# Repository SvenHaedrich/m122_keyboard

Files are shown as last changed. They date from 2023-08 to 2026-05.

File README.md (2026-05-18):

# m122_keyboard

Project for an IBM M122 keyboard controller

This is a project that replaces the original part from IBM with a nice modern solution.
It features a nRF52840 microcontroller and allows to use the keyboard
via USB connector, or via Bluetooth.

The firmware is based on the [ZMK](https://github.com/zmkfirmware) project.

Assembled PCB

## Parts

Beside the assembled PCB you require:

- A matching IBM Keyboard
- An external LiPO cell - the unit was designed with a LP103048JU 1.500 m Ah cell in mind
- One 8 pin connector for the flat flex coming from the keyboad 5-520315-8 from [AMP](doc/ENG_CD_520355_L2.pdf) DigiKey P/N 5-520315-8-ND
- One 20 pin connector for the flat flex coming from the keyboad 7-520355-0 from [AMP](doc/ENG_CD_520355_L2.pdf) DigiKey P/N A144436-ND

## Tools

You need a debug adapter (JLink) with 6 pin [Tag-Connect](https://www.tag-connect.com) for the initial flash programming of the board

## Order

When ordering the pcb from [JLC](https://jlcpcb.com) you need to specify

- Via Covering Epoxy Filled & Capped
- Min via hole size 0.2 mm

## Initial Setup

- Use the nrf-Flash-Tool to flash the bootloader to the nrf52840
- Use drag-and-drop of the uf2 build output to flash the keyboard firmware

## Build the Firmware

`push` and `pull_request` trigger a github-action to build the firmware. To locate the build output
go to the `Actions` tab and open the respective workflow run. There you find a link to the artifacts
generated by the run. You can download it and unpack the `.zip` archive to access the `.UF2` file.

This repository follows the versions of the ZMK project.
For details, please refer to the [Release Log](docs/releases.md).

## Update Firmware

To update the firmware activate the bootloader.
By default you can start the bootloader by hitting the `bootloader` key.
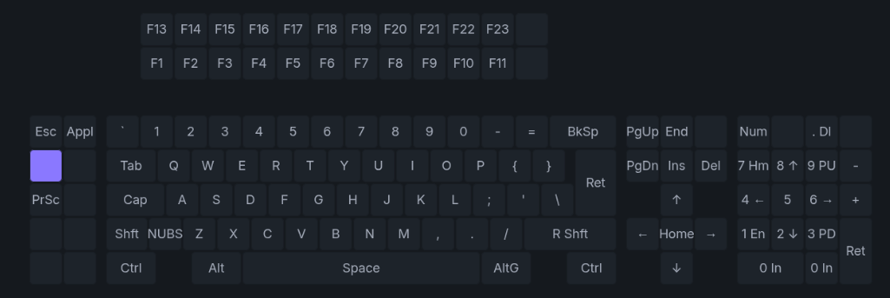
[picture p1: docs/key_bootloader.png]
Bootloader key

If successful, this will mount your keyboard as a USB mass storage device to your computer.
Now, you can install the firmware by simply drag and drop the UF2 file to the mounted device.

## Connect to ZMK Studio

To connect the keyboard to ZMK Studio open this [link](https://zmk.studio/).
Google's chrome is the preferred browser for this app.
Select the connection to your keyboard.
You need to press the `studio unlock` key on your keyboard to establish the connection.
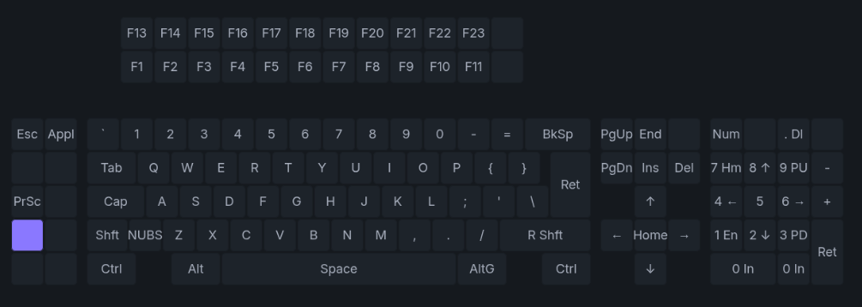
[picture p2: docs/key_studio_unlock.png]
Studio unlock key


## Bootloader

The project uses a modified [Adafruit](https://github.com/SvenHaedrich/Adafruit_nRF52_Bootloader.git) bootloader.

## Testing

You might want to test the basic electric functionality of the PCB. To do so, flash the firmware and connect the PCB to a computer´s USB port.
To view detailled event codes start

```bash
sudo evtest
```

Select your M122 controller as event source. Now, you can short individual rows and columns. Expected results are given for German keyboard layout.

| Row | Column | Keycode |
|-----|---|---|
|  1  | 16 | KEY_KP0 |
|  1  | 8 | KEY_B |
|  2  | 8 | KEY_V |
|  3  | 13 | KEY_RIGHTBRACE |
|  4  | 5 | KEY_Q |
|  5  | 9 | KEY_6 |
|  6  | 12 | KEY_F5 |
|  7  | 1 | KEY_PPLUS |
|  8  | 15 | KEY_APOSTROPHE |
|  2  | 2 | KEY_KP1 |
|  2  | 3 | KEY_CAPSLOCK |
|  1  | 4 | KEY_LEFTSHIFT  |
|  1  | 20 | KEY_ENTER |
|  1  | 19 | KEY_KPCOMMA |
|  2  | 18 | KEY_KP2 |
|  2  | 17 | KEY_INSERT |
|  4  | 15 | KEY_P |
|  6  | 14 | KEY_9 |
|  4  | 11 | KEY_F7 |
|  3  | 10 | KEY_F20 |
|  7  | 6 | KEY_S |
|  7  | 7 | KEY_D |

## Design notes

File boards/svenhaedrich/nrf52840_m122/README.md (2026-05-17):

# nrf52840_m122

Driver board for the IBM M122 mechanical keyboard, based on the nrf52840.
The board schematics and PCB is available at: <https://github.com/SvenHaedrich/m122_keyboard>

## Building nrf52840_m122 Firmware

Build the standard version locally using, assuming your board files are found in the (..) directory:

```bash
west build --board nrf52840_m122//zmk \ . -- -DBOARD_ROOT=(..)/m122_keyboard -DCONFIG_ZMK_STUDIO=y
```

To enable ZMK-Studio support use the following command to build:

```bash
west build --board nrf52840_m122//zmk -S studio-rpc-usb-uart  . -- -DBOARD_ROOT=(..)/m122_keyboard -DCONFIG_ZMK_STUDIO=y
```

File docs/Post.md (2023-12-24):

__Total Makeover of a Model M122 aka Battlecruiser__

This is the story of my journey to bring todays technology to an IBM M122 keyboard. 
I started my professional carrer as a computer developer using the monsterous IBM keyboards that came with the IBM data terminals. 
Now, I wanted to bring back some nostalgic feelings into my everyday prodfessional live.
Notwithstanding the superior mechanical qualities of a beast that features a steel plate as a source for mechanical robustness and precision.

__The Beginning__

My first step was to order a surviving specimen of the IBM M122 from Ebay. 
I found one that is in pretty good nick.
My baby has a German ISO Layout, built in January 1992, and the part number reads 139 4312.
I decided to discard the slightly discussting crusted connection cord.
Furthermore, I investigated the options to add adapters to the original keyboard controller and decided that all the available converters are more makeshift solutions than anything else.
Being a professional embedded developer I accepted the challenge to provide a more modern interface solution for the classic piece of hardware.
I wanted my keyboard to have full support for all these fantastic keys, a USB HID connection, Bluetooth connectivity.
After some investigation I decided to use the ZMK firmware package running on a Nordic nRF52840 as the route to follow.

__The Hardware__

Before commiting myself to expensive and time consuming hardware designs, I wanted to check the feasibility of my project. 
First step was ordering the flatcable connectors. 
Original connectors are still available from Digikey. 
I soldered a pair of connectors to prototype boards, added resistors to the row connection and used a plethora of jumper cables to connect everything with a Nordic nrf52840 development kit.
There are plenty of alternative boards to the Nordic kit available but most hobbyist boards lack the full set of general purpose ports.
The M122 uses a key matrix with 8 rows and 20 columns. 
So, 28 pins are necessary to drive the keyboard matrix.
In principle one could use interface expanders to have more port pins available, it just feels less elegant than doing everything with a single controller chip.
The development kit based contraption prooved to be relatively reliable, I used my keyboard for weeks in this configuration. 
Though, the missing outer shell gave the whole set up the look of a prop for a dystopian movie.

Set-up with development kit

Taking the operational development kit version as a starting point I developed a PCB for my M122 using KiCAD as design tool.
My idea was to create a drop in replacement for the existing controller.
This solves all the PCB-mounting and flat flex cable routing issues at the cost of a rather large and expensive PCB. 
But, in the end the whole project is not about saving money.
For the Bluetooth antenna I decided to go with a PCB antenna, I do not need high efficiency antenna operation to bridge the usual distances on my desktop.
For USB I use a type C connector, of course.
The nRF controller cames with a challenge on its own.
The controller comes in an "aQFN" package that calls for advanced PCB manufacturing technologies.
I was not sure that my board layout would actually work, and not sure about the reliablility of the production process.
So, I procastrinated the order at JLCPCB for some weeks until I finally collected enough strength and self-confidence to place it.
I decided that blue is the colour of choice for this project, because you know, _Big Blue_. 
When I received the first iteration of the PCB I found out that I miscalculated one mounting hole position and messed up the footprint of the high speed quarz.

First version of my PCB

After a final touch to the pcb layout I placed an order for the next iteration with JLC. 
This time it worked like a charm.
The new board replaces perfectly the original board.
For Bluetooth operation the keyboard is powered from a recharheable power pack.
For my personal taste it is fine to glue this pack with a strip of gaffer type.
I tell myself that I avoid unnecessary mechanical stress on the delicate cells.

Final PCB version

The board has a reset button which can be really useful as the board can run from battery power a fact that makes power down resets practically impossible.
I admit that I drilled a small hole into the outer shell of the keyboard to allow actuation of the button by the a mangled paperclip. 
Still left on my to-do list is a nice feedthrough for the USB cable. For now I just have the cable dangling out of the original outlet. This is connected to the USB connector on the controller PCB.

__The Firmware__

Firstly, let me state that Zephyr is the future for embedded software development. 
That being said, ZMK was the obvious choice for my project.
The symbiosis between Nordic Semiconductor and the Zepyhr project makes it a breeze to work with that combination.
I started out from one of the many nrf52840 based keyboard projects.
All I needed to do was to modify device tree defintions to match my GPIO port configuration and keyboard layout.
Fortunately, clever people before me already explored the key matrix of the IBM M122.
So, I spend more time of the firmware development searching typos in my device tree than anything else.
Once I received my final hardware making the step from the development kit GPIO configuration to the final configuration for my own PCB layout was made in no-time.
I followed the choice from the ZMK project to use the Adafruit bootloader, mostly because I was too lazy to set a bootloader with MCUBOOT up.
Actually, I had the intention to upstream my board configuration files, until I learned that ZMK only upstream boards that are commercially avialable, or already attracted larger communities.
In summary I can only stress that everything worked _out of the box_. I never had to dive into the keyboard matrix driver, the USB interface, or the Bluetooth protocol.

__The Result__

The beaty

Everthing works as expected. The keyboard is my everyday workhorse.

__The Documentation__

All resources that are needed to redo my makeover adventure are published on https://github.com/SvenHaedrich/m122_keyboard.

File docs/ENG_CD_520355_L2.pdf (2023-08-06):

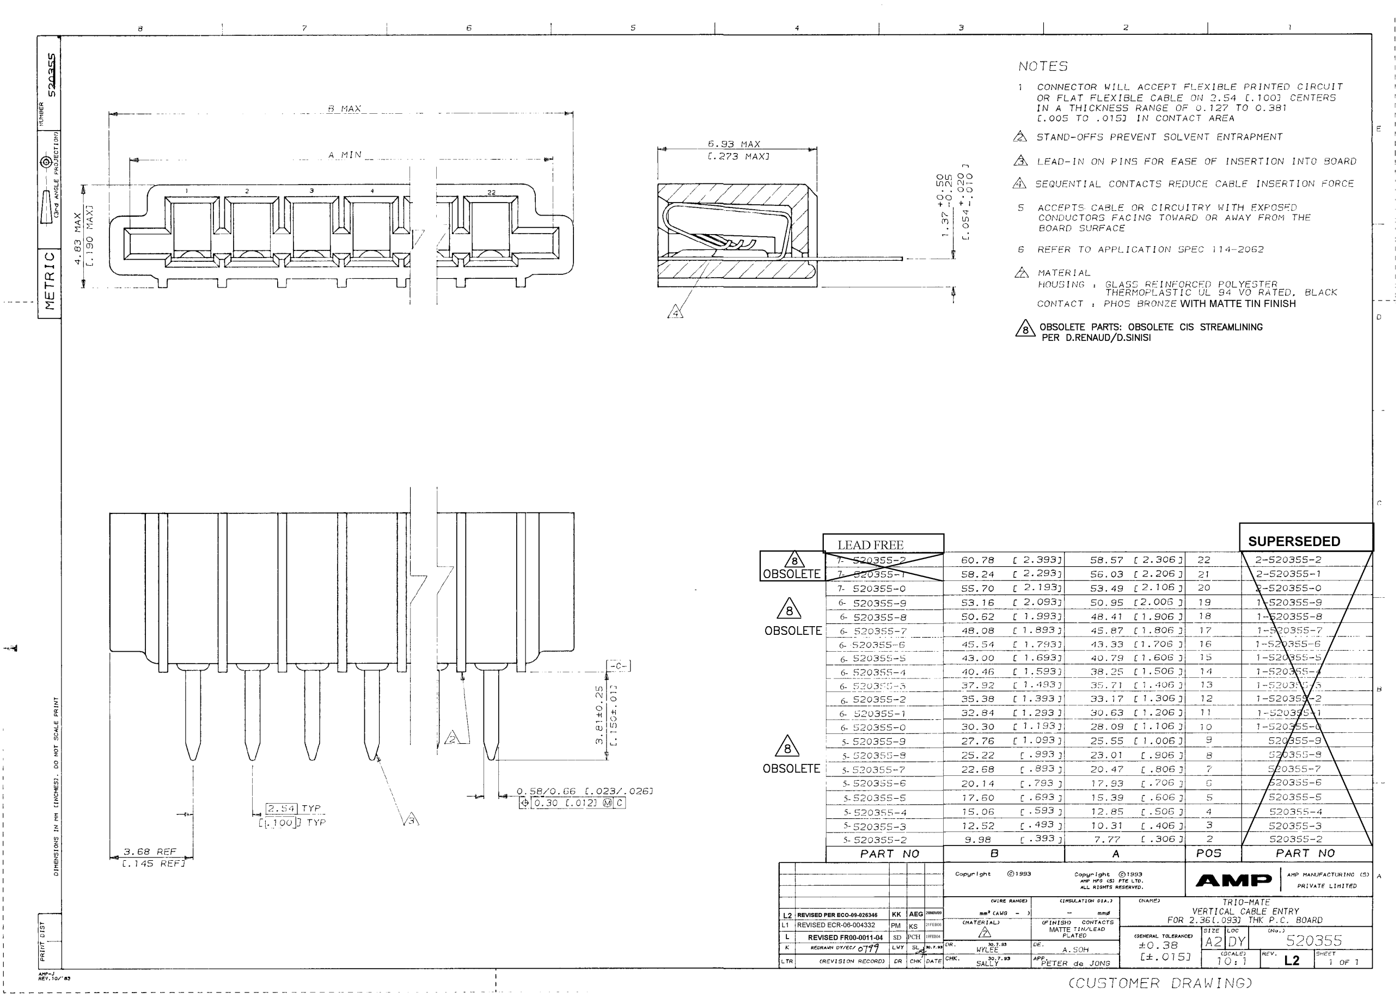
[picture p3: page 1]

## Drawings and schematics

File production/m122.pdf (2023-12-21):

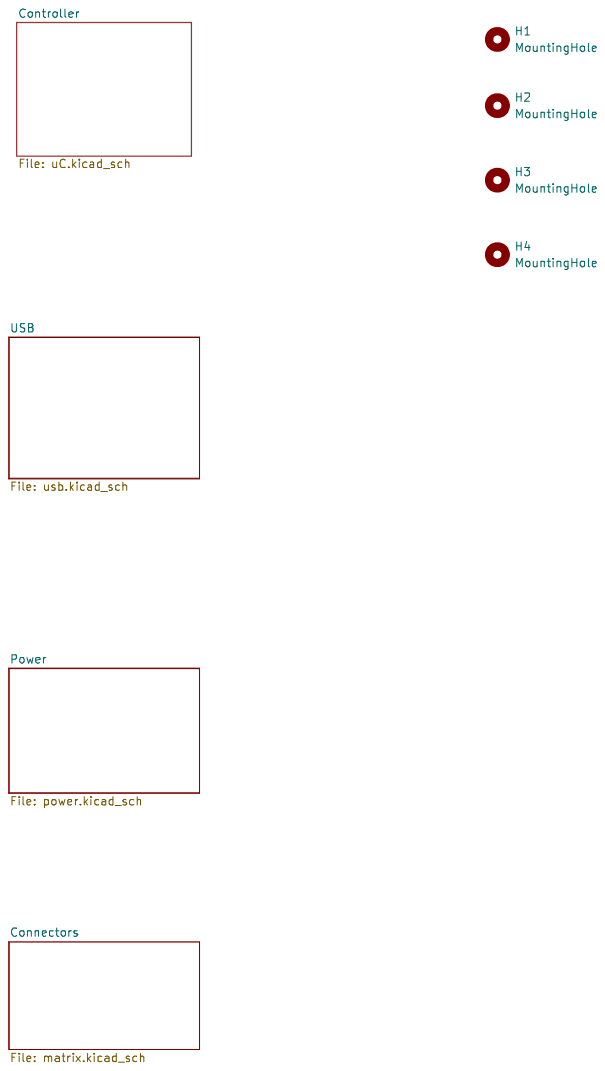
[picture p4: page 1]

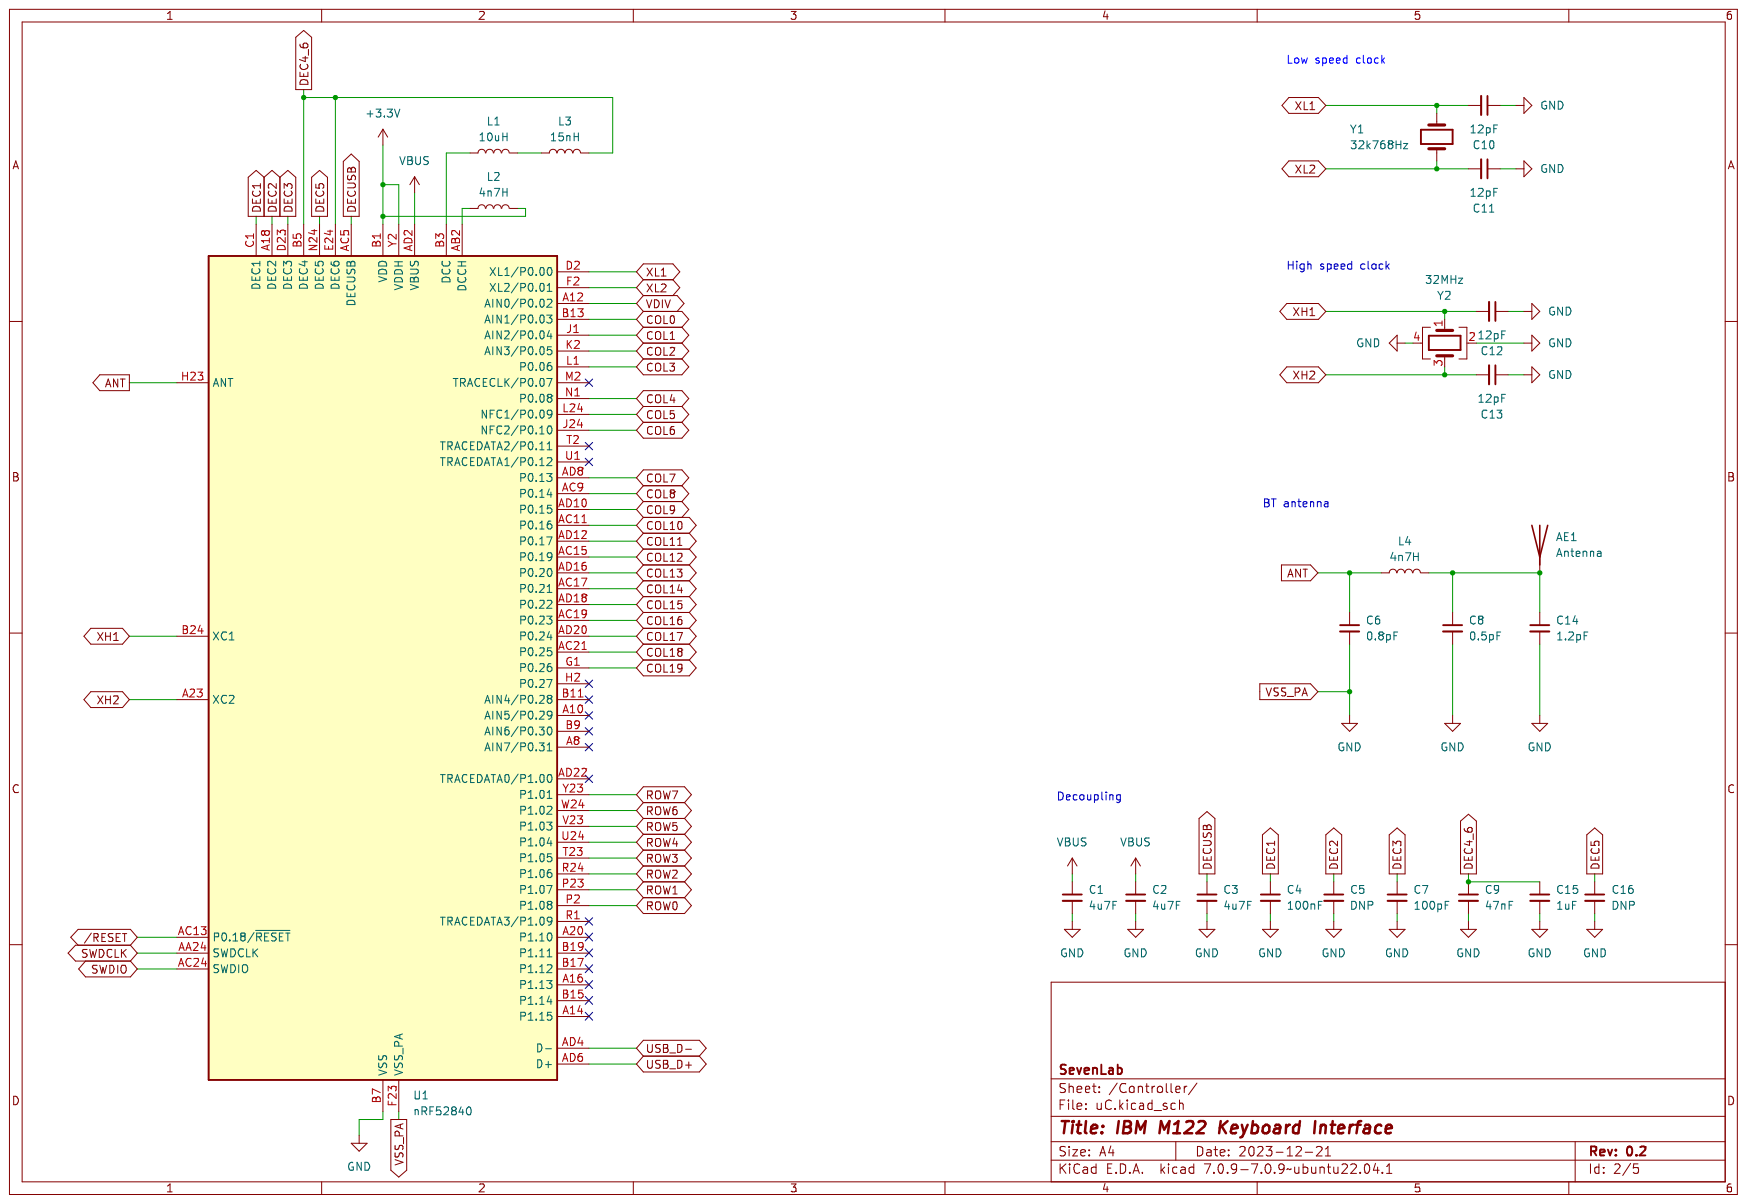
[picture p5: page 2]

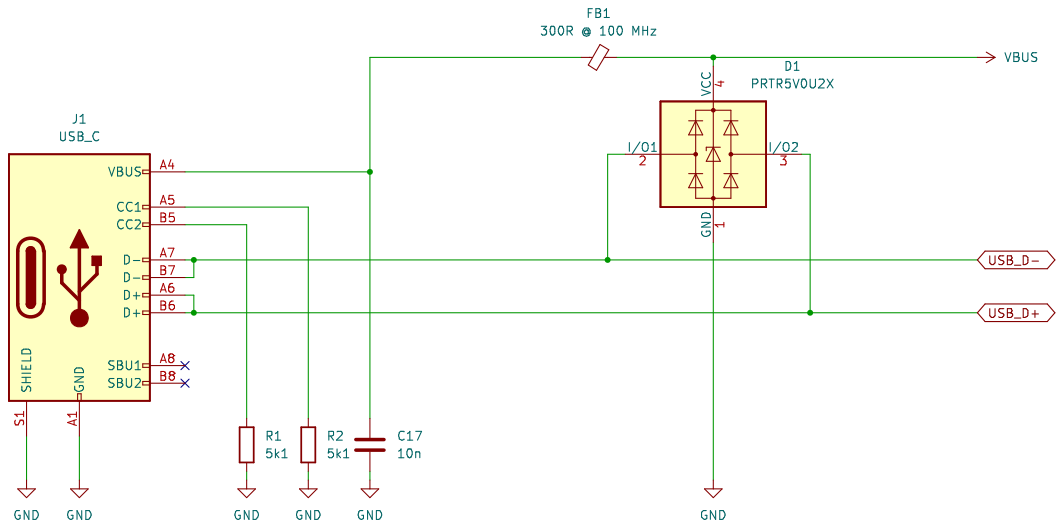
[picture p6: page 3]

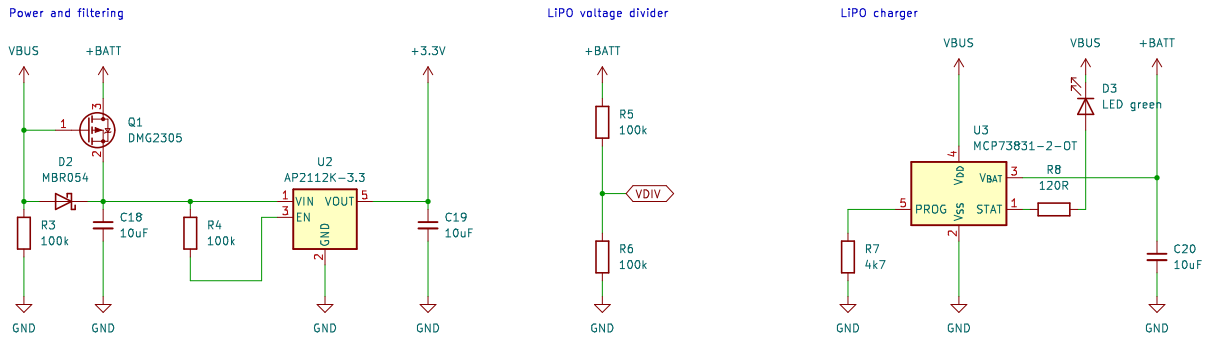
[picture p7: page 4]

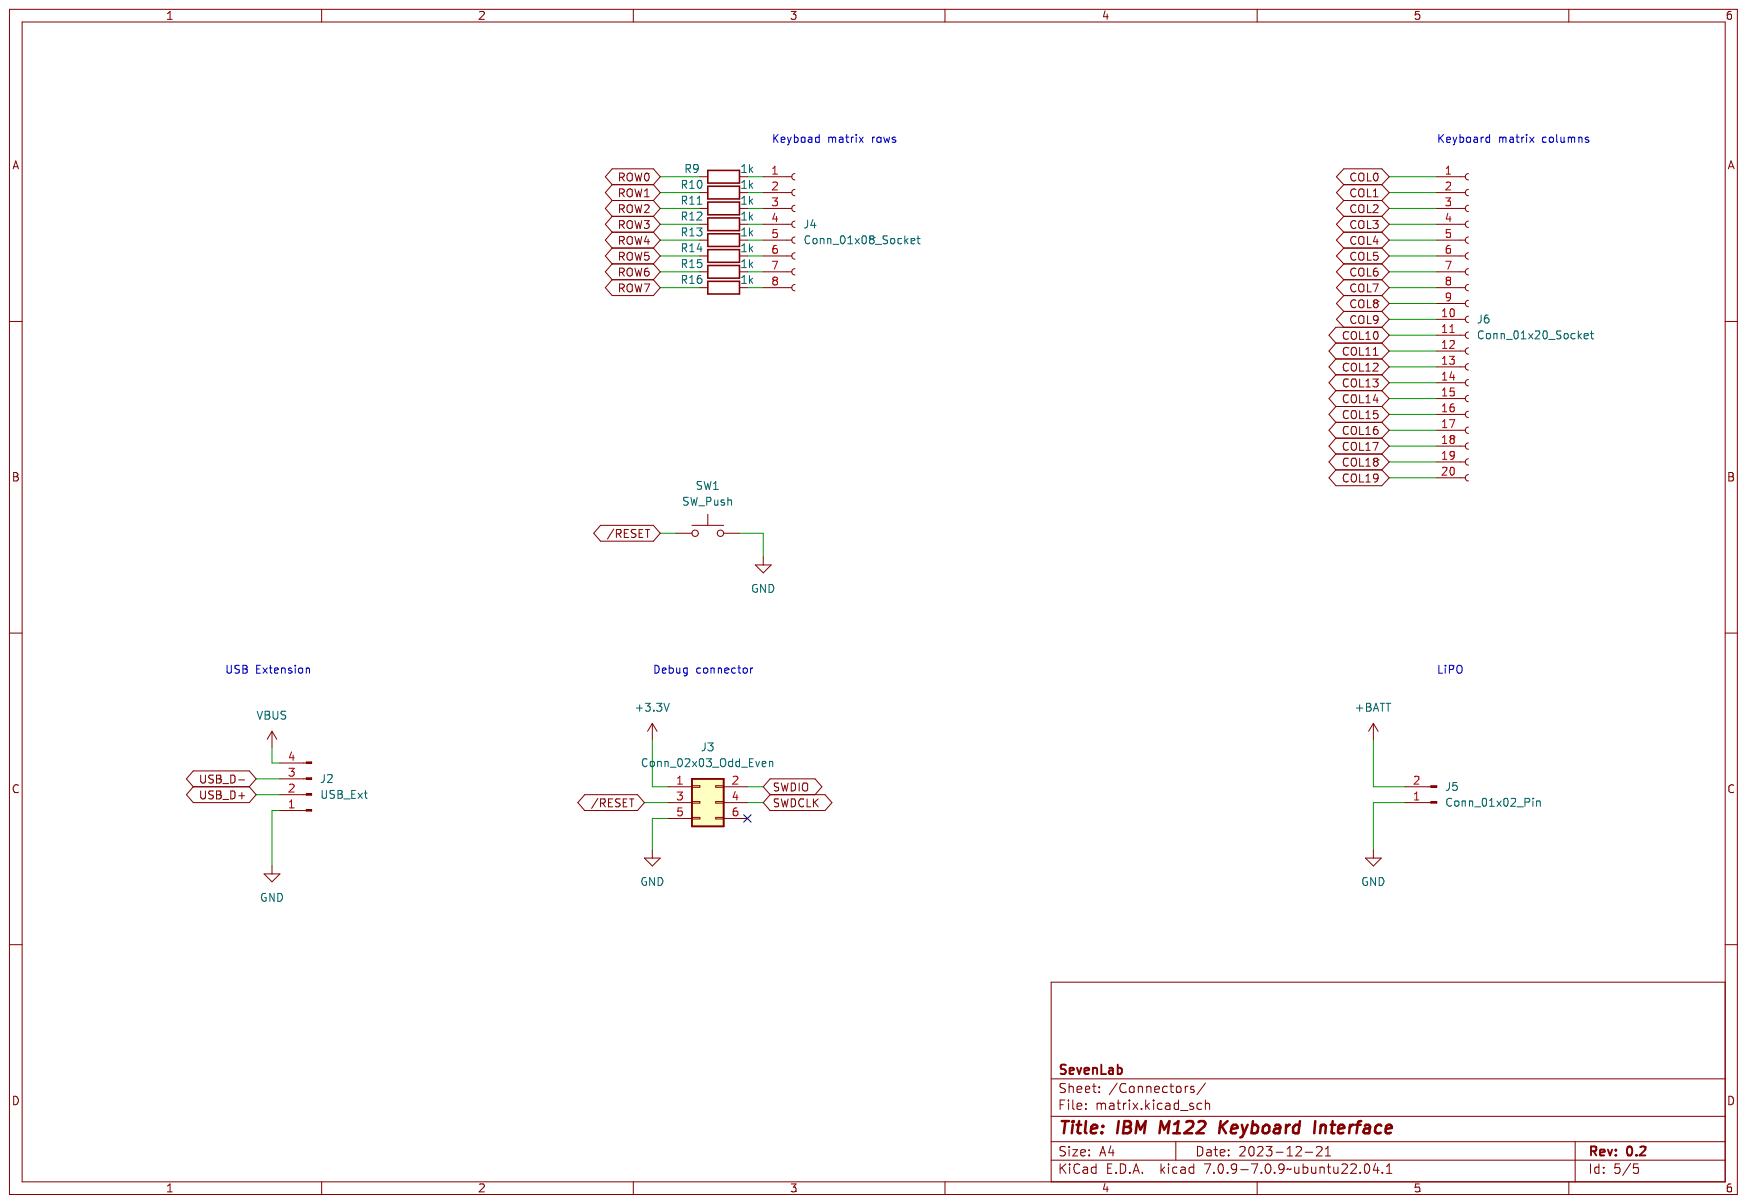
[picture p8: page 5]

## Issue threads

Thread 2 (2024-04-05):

programming the board

bulnv, 2024-04-05:
Hello Sven! I was trying to reach out to you in deskthority forum. Here is my question:

I recently found your 122 key ibm restoration project and really excited about it. I'm an doing right now the same. I have a board without controller and I'd wanted to reuse your PCB design. I am mostly software guy, and only one thing is confusing me it's a initial firmware with some jtag. Is it kinda must and there no other way ways like usb? If so, can you please point me the correct one flashing device? Thanks!

SvenHaedrich, 2024-04-06:
Obviously, GitHub has a better connection to me than deskthority.net.

I never bothered to find out how to flash the nRF without a SWD programmer at hand. As far as I recall there is no hardcoded bootloader included in the nRF. So, you have two options:

(1) If you want to replicate my hardware: I still have some PCBs left. I can flash a bootloader and a keyboard driver onto the  board before I send it out to you. Once you have a bootloader installed you can flash the keyboard driver via drag´n´drop to the controller.
(2) If you want to modify the layout: you can swap the TAG connect (actually the connector would be more expensive than a programmer) to something more common and use a variety of programmers to flash the board (see e.g. https://github.com/kholia/xvc-pico/ )

bulnv, 2024-04-06:
Hello! Thanks for response. Having PCB from you would be the best option I could imagine, especially preflashed. My email is nvbulashev@gmail.com.

SvenHaedrich, 2024-04-07:
You have mail.

GrimbleFitz, 2024-04-23:
Hey Sven! I also noticed your post on Deskthority and would be very appreciative if you still had some PCBs left. I've got a couple of m122's without controllers that I've been hoping to engineer some sort of battery+wireless ZMK solution for. My email is kile@fitz.farm, if you don't mind me chiming in like this.

SvenHaedrich, 2024-05-22:
Issues solved.

Closed 2024-05-22.

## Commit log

2023-08-05 work in progress. basic schematic is ready
    [m122.kicad_pcb, m122.kicad_sch, matrix.kicad_sch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]
2023-08-06 BOM is ready
    [matrix.kicad_sch, power.kicad_sch, uC.kicad_sch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]
2023-12-09 All changes for version 0-2
    [m122.kicad_pcb, m122.kicad_sch, uC.kicad_sch]
2023-12-21 Adjust title block
    [m122.kicad_sch, matrix.kicad_sch, power.kicad_sch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]
2023-12-23 Add an image of the finished PCB
2024-05-22 Remove unnecessary include file.
    This board supports no LEDs.
2024-05-22 Update for KiCAD 8.0.
    Use the default import suggestions.
    [m122.kicad_sch, matrix.kicad_sch, power.kicad_sch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]
2024-05-22 Add test description
    Add a test that uses all row amd
    column gpios to verify function
    of board and firmware.
2024-05-23 Add a board to the build.yaml
2024-08-18 Disable RTT logging
    This solves the problem with the
    keyboard stalling, when Bluetooth
    is enabled and no JLink connected.
    That should not be a problem, but
    obviously it is.
2026-05-15 Build the project with ZMK v0.3.0
    Pin the ZMK version for the build process.
    Remove instructions to build locally from the README.md.
2026-05-15 Pin build process to latest
2026-05-17 Update the board files.
    Re-arrange, rename and use the latest dependencies so that
    the board is build.
